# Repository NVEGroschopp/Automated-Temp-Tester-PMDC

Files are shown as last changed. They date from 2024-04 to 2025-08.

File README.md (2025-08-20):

# Automated Temperature Tester PMDC

## Overview
The Automated Temperature Tester PMDC project utilizes an Arduino Nano 33 BLE, a K-Type Thermocouple, a Max6675 Breakout Board, an induction coil, and 3D printed fixtures. This document serves as a comprehensive guide for assembly, wiring, and usage of the automated temperature test LabVIEW program.

## Components
- [Arduino Nano 33 BLE Rev1](https://store-usa.arduino.cc/products/arduino-nano-33-ble-with-headers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)
- K-Type Thermocouple
- [Max6675 Breakout Board](https://a.co/d/3DE7FEz)
- [Induction coils](https://a.co/d/aSvJQnv)
- [BLED112 USB Dongle](https://www.digikey.com/short/ch5m7prf)
- Customized Shims for Bearing
- Customized Endbell for Different Frame Size
- 3D Printed Fixtures
- External 5V power supply

## Description
This automated tester device serves as a transmitter that sends temperature data through the air using Bluetooth Low Energy module to the host LabVIEW program (Eng lab computer/Desktop/Automated Temp Test/PM Automated Temperature Test Final).

## Wiring Diagram
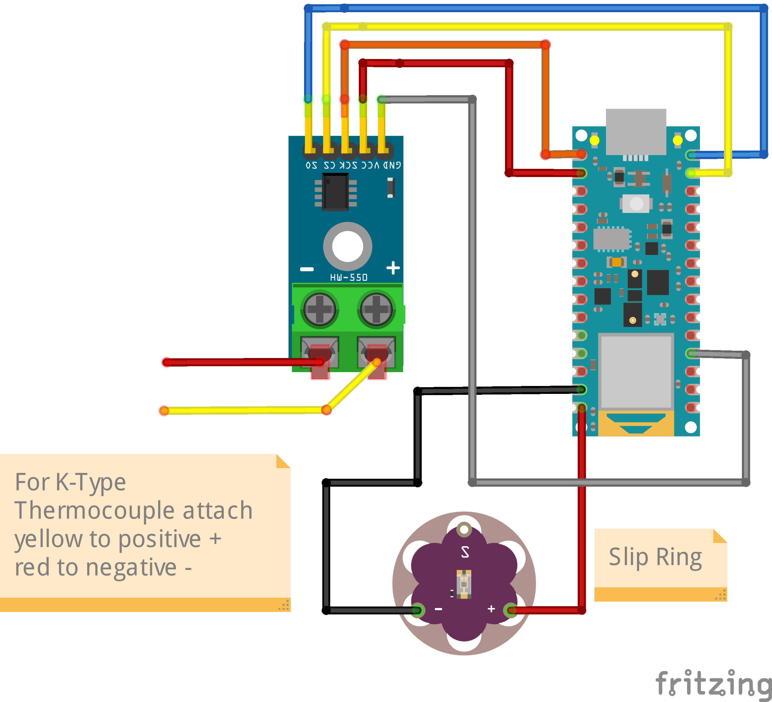
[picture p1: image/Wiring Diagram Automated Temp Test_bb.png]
Wiring Diagram Automated Temp Test


Assembly (Exploded)

## Installation and Setup
1. Assemble the components according to the diagram and assembly print (reference X-20604 for assembly prints). View the Assembly Documentation PDF for more detailed information on assembly.
2. Upload the Arduino sketch to the Arduino Nano 33 BLE.
3. Attach the thermocouple to the armature winding.
4. Feed the thermocouple through the bearing and attach the yellow to positive + and red to negative - on the breakout board.
5. Attach the device at the end of the modular shaft.

[Assembly Documentation.pdf](https://github.com/user-attachments/files/21864532/Assembly.Documentation.pdf)

## Usage
1. Start by adjusting the PID for the brake.
2. Select the correct model for the brake and send the configuration.
3. Enter the correct addresses for each device (see below) and check all physical connections.
4. Set the power supply to the correct voltage and run the motor.
5. Turn on the brake fan.
6. Hit the Start button to start the program.

**The device needs to be restarted when starting a new test.**

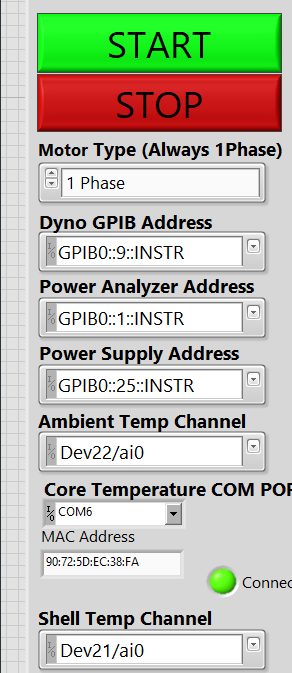
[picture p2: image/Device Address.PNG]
Device Address


Note: The MAC address for the Arduino board varies. The default MAC address for the prototype device is 90:72:5D:EC:38:FA.
For other devices that use a new Arduino board, find the MAC address using the LabVIEW subvi located at Eng lab computer/This PC/Desktop/ble_read_temperature.vi

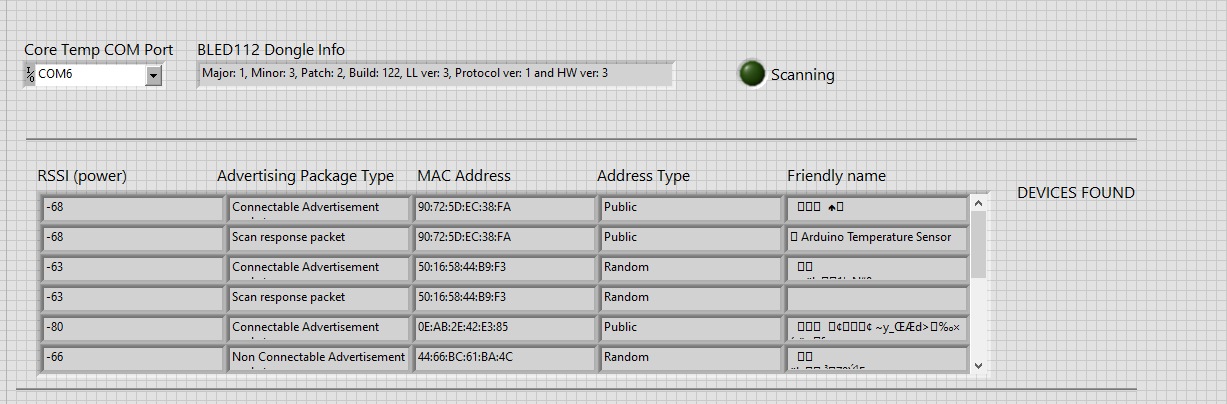
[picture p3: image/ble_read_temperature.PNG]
Ble Labview VI


Choose the correct COM port which BLED112 USB Dongle is located.
Start the VI and capture the Mac Address for the device named as Arduino Temperature Sensor, copy and paste the MAC address to the main program.
## Troubleshooting
If you encounter any issues during setup or usage, refer to the following troubleshooting steps:
- Try restart the power analyser, power supply and brake controller by turning them off and back on.
- Restart the computer and check the connections of GPIB to USB cable.
- Restart the device by shutting off the external power supply.

## Conclusion
When test is complete save the raw data under H:\Eng\ENGINEERS\Tong\Class F Catolog Tem Test Data\RawData and process the data using the Excel Macro-Enabled Worksheet located under H:\Eng\ENGINEERS\Tong\ PM Automated Temperature Test Form by copying raw data to sheet2.

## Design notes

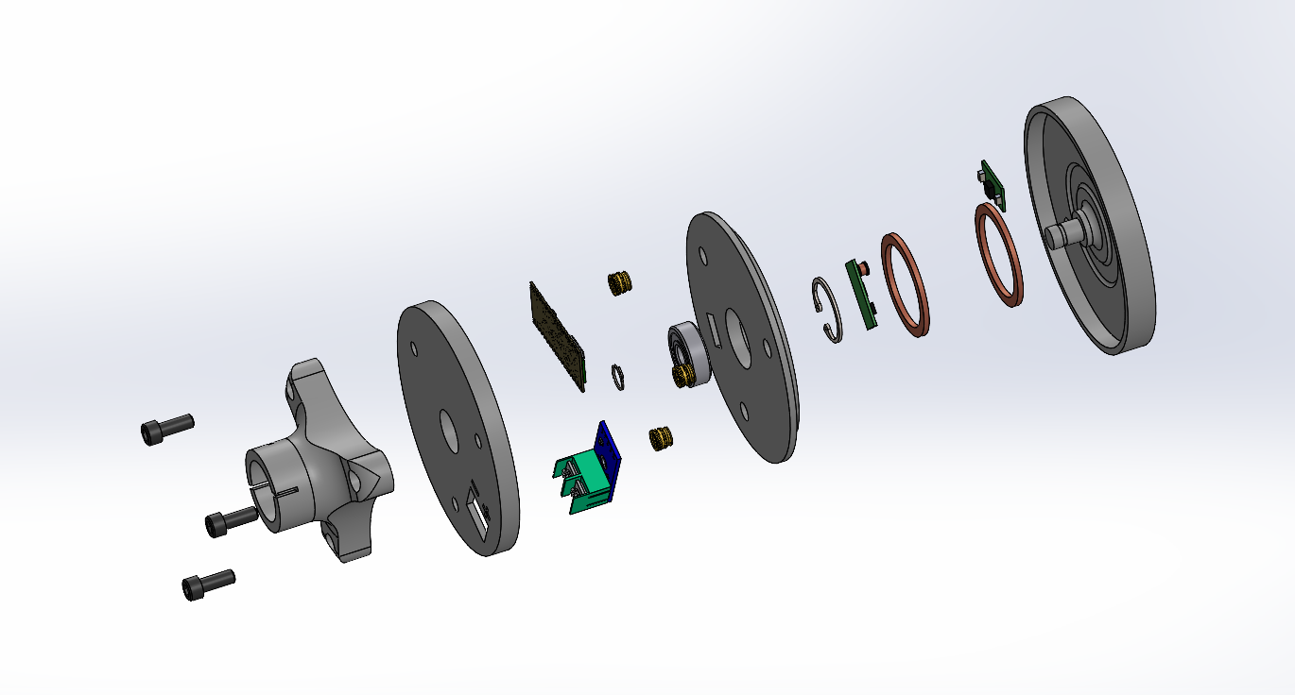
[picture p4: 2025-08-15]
image/Screenshot 2025-08-15 124119.png

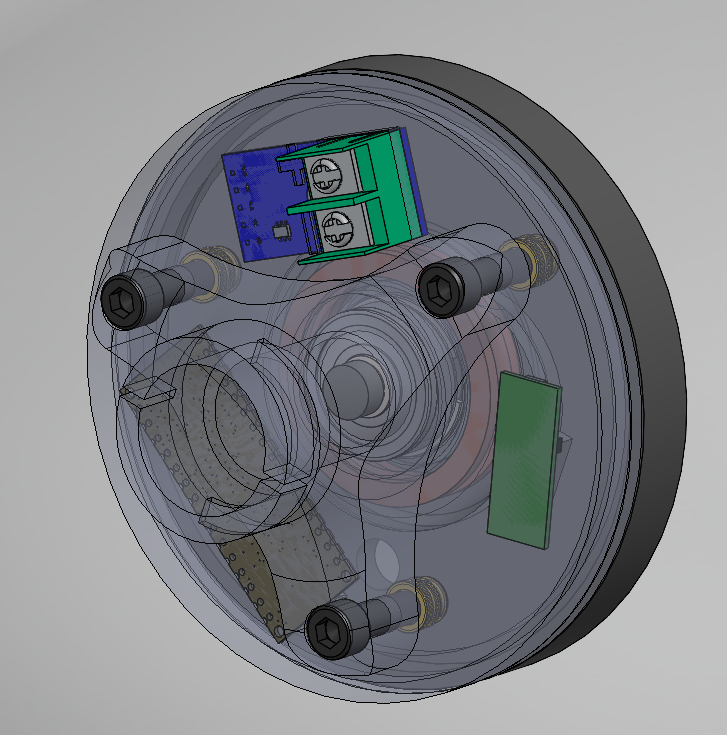
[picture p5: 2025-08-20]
image/Screenshot 2025-08-20 080611.png

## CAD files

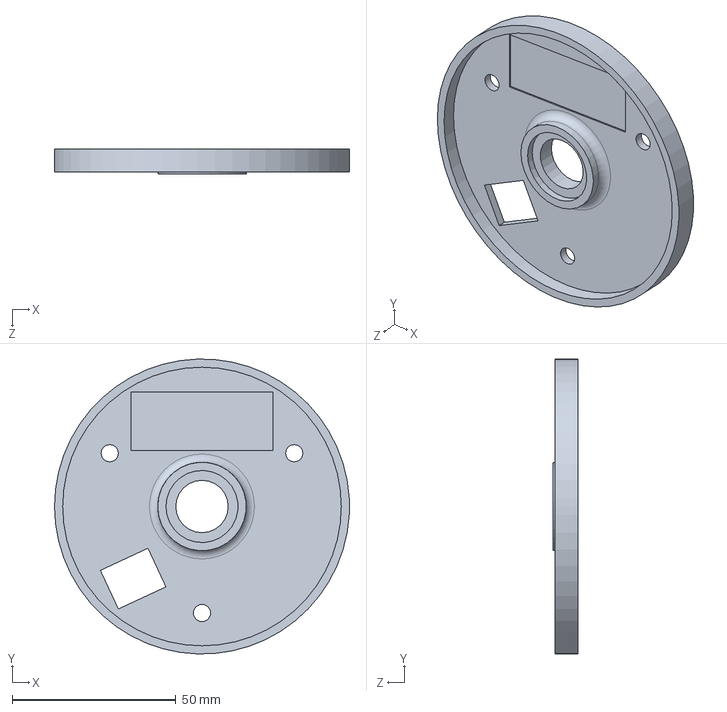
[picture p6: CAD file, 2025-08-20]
3d Printed/Board Compartment.SLDPRT
90.0 x 90.0 x 7.50 mm

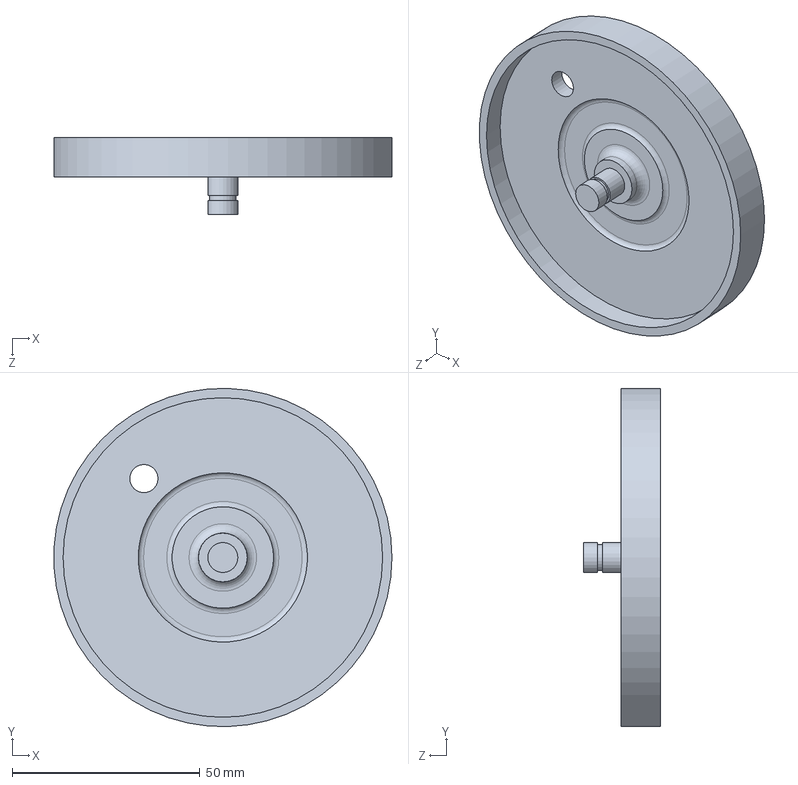
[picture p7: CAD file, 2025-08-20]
3d Printed/Transmitter Compartment.SLDPRT
89.9 x 90.0 x 20.5 mm

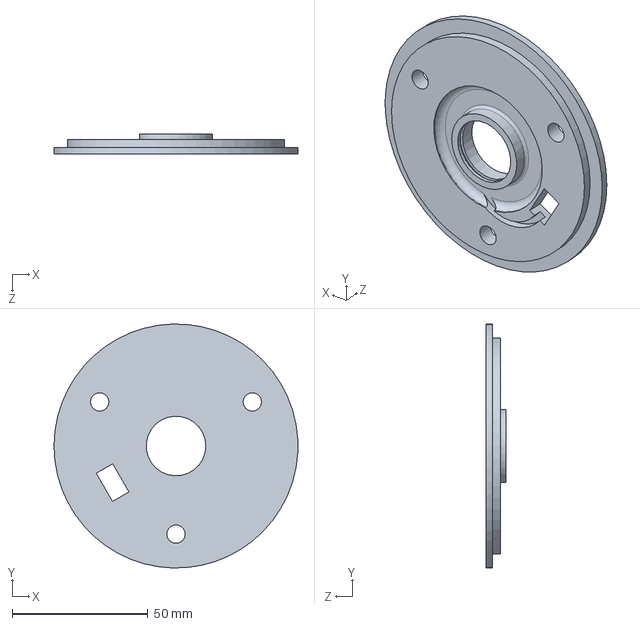
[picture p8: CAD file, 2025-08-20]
3d Printed/Reciever Compartment.SLDPRT
90.0 x 90.0 x 7.50 mm

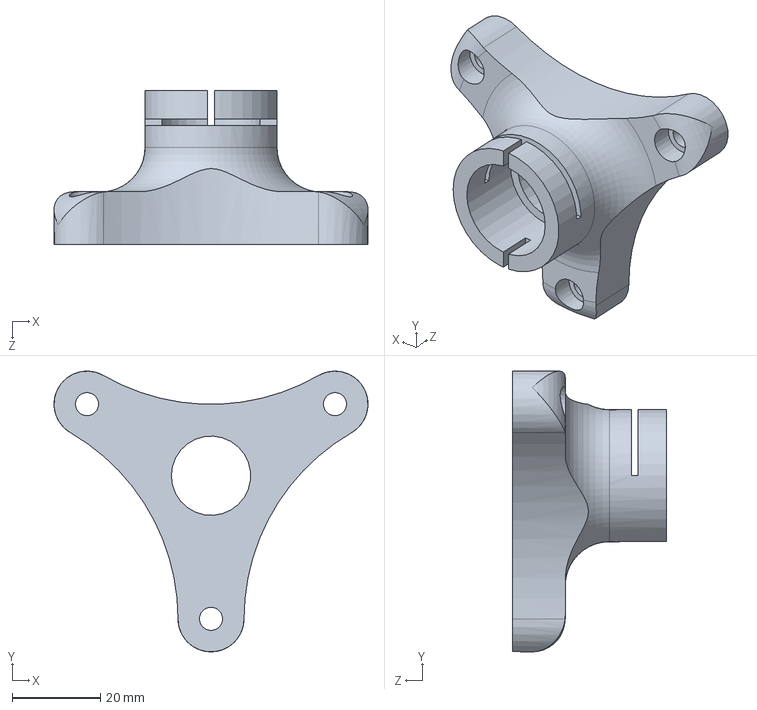
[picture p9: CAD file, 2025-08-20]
3d Printed/coupler.SLDPRT
71.3 x 63.7 x 35.0 mm

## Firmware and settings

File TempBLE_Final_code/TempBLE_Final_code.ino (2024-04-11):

#include <ArduinoBLE.h>           // Bluetooth Library
#include "max6675.h"              // Breakout board Libray by Adafruit

// Initalizing global variables for sensor data to pass onto BLE
int thermoSO = 12;
int thermoCS = 11;
int thermoCLK = 13;

String t;

MAX6675 thermocouple(thermoCLK, thermoCS, thermoSO);
// BLE Service Name
BLEService customService("180C");

// BLE Characteristics
// Syntax: BLE<DATATYPE>Characteristic <NAME>(<UUID>, <PROPERTIES>, <DATA LENGTH>)

BLEStringCharacteristic ble_temperature("2A57", BLERead | BLENotify, 13);


// Function prototype
void readValues();

void setup()
{
    // Initalizing all the sensors
    delay(2000);
    
    if (!BLE.begin())
    {
        while (1);
    }

    // Setting BLE Name
    BLE.setLocalName("Arduino Temperature Sensor");
    
    // Setting BLE Service Advertisment
    BLE.setAdvertisedService(customService);
    
    // Adding characteristics to BLE Service Advertisment
    
    customService.addCharacteristic(ble_temperature);

    // Adding the service to the BLE stack
    BLE.addService(customService);

    // Start advertising
    BLE.advertise();
}

void loop()
{
    // Variable to check if cetral device is connected
    BLEDevice central = BLE.central();
    if (central)
    {
        while (central.connected())
        {
            delay(200);
            
            // Read values from sensors
            readValues();

            // Writing sensor values to the characteristic
            
            ble_temperature.writeValue(t);
        }
    }
}

void readValues()
{
    // Reading raw sensor values from three sensors
    float x;
    float temperature = thermocouple.readCelsius();

    // Saving sensor values into a user presentable way with units
    t = String(temperature);
}

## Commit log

2025-06-10 Delete image/Automated Temp Tester.png
    Delete current module image view
2025-08-15 Update Picture
    Added new screenshot of SOLIDWORKS assembly
2025-08-19 Update README.md
    Added "Assembly Documentation" pdf
2025-08-20 Added File
    uploaded .SLDPRT files for the 3d-printed fixtures
    [Board Compartment.SLDPRT, Reciever Compartment.SLDPRT, Transmitter Compartment.SLDPRT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]
2025-08-20 Add file
    add updated assembly
